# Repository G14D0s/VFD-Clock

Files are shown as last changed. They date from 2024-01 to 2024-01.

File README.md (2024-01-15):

# VFD-Clock
Mein Projekt für LF06: Das Wiedererwecken einer Fluoreszenz-Anzeige. 

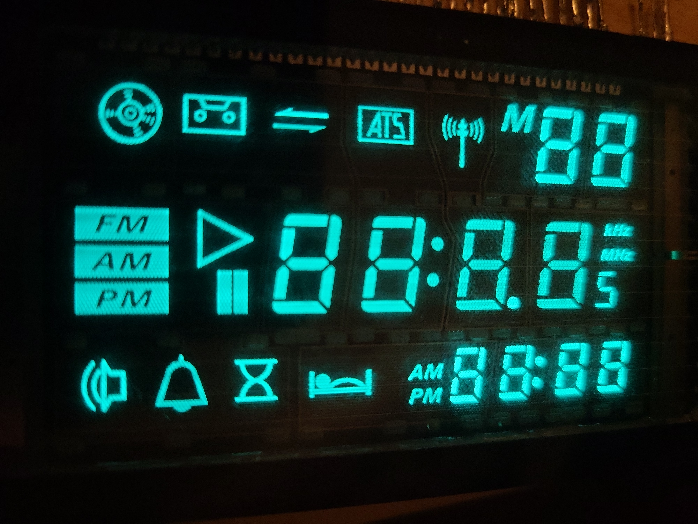
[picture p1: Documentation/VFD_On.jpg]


# Ressourcen
Die Dokumentation / Ausarbeitung findet sich hier:
* [VFD - Ausarbeitung](Documentation/VFD-Ausarbeitung.md)
* [Videos](https://drive.google.com/drive/folders/1unJfzBfumFYsPnYGjSA5P8ESAhW6MluK?usp=sharing)
* [neuester Release mit PDF](https://github.com/G14D0s/VFD-Clock/releases/tag/Release)

***
# Diagramme
Mit [Obsidian](https://obsidian.md/) habe ich folgende Canvas-Dateien erstellt:
* [elektrischer Aufbau/Verbindungen](Documentation/VFD-Aufbau.png)
* [Konzept Programmierung](Documentation/VFD-Bildschirm_Programmierung.png)
* [Ablauf Multiplexing](Documentation/Ablauf_Multiplexing_VFD.png)

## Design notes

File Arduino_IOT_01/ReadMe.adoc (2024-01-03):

:Author: G14D0s
:Email:
:Date: 18/10/2023
:Revision: version#
:License: Public Domain

= Project: {Project}

Describe your project

== Step 1: Installation
Please describe the steps to install this project.

For example:

1. Open this file
2. Edit as you like
3. Release to the World!

== Step 2: Assemble the circuit

Assemble the circuit following the diagram layout.png attached to the sketch

== Step 3: Load the code

Upload the code contained in this sketch on to your board

=== Folder structure

....
 sketch123                => Arduino sketch folder
  ├── sketch123.ino       => main Arduino file
  ├── schematics.png      => (optional) an image of the required schematics
  ├── layout.png          => (optional) an image of the layout
  └── ReadMe.adoc         => this file
....

=== License
This project is released under a {License} License.

=== Contributing
To contribute to this project please contact: 

=== BOM
Add the bill of the materials you need for this project.

|===
| ID | Part name      | Part number | Quantity
| R1 | 10k Resistor   | 1234-abcd   | 10       
| L1 | Red LED        | 2345-asdf   | 5        
| A1 | Arduino Zero   | ABX00066    | 1        
|===

=== Help
This document is written in the _AsciiDoc_ format, a markup language to describe documents. 
If you need help you can search the http://www.methods.co.nz/asciidoc[AsciiDoc homepage]
or consult the http://powerman.name/doc/asciidoc[AsciiDoc cheatsheet]

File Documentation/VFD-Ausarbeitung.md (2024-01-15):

---
tags:
  - Projekte/VFD-Wecker
---
Florian Hoos, EATb26 - 2024-01-15
VFD_On.jpg|600
# 1. Auswahl der Schaltung
Für dieses Projekt habe ich mich entschieden, eine alte Fluoreszenz-Anzeige aus einem auseinandergenommenen Küchenradio wieder funktionstüchtig zu machen. Es handelt sich um ein *Vacuum Fluorescent Display* mit mehreren 7-Segment-Anzeigen und einigen Symbolen auf insgesamt 11 Feldern.
## Warum habe ich diese Schaltung gewählt?
Ich habe die Schaltung der Fluoreszenz-Anzeige gewählt, da sie einige interessante Mechanismen und Funktionsweisen der Elektronik in Anwendung zeigt. Fluoreszenzanzeigen wurden schon vor Jahrzehnten durch LED-Anzeigen ersetzt, die leichter anzusteuern, günstiger zu produzieren und kompakter zu bauen sind. Da wir in Lernfeld 06 aber sowieso "back to basics" gehen und zum Beispiel analoge Transistorschaltungen analysieren, finde ich es sehr passend.
## Welche Problematik löst die Schaltung?
Grundlegend löst die Schaltung kein explizites Problem in meinem Leben. Als historisches Bauteil bietet die Fluoreszenzanzeige aber interessante Vorteile gegenüber regulären LED-Anzeigen. 
So haben sie eine hohe Lebensdauer, einen weiten Sichtwinkel und, zumindest in der Theorie, eine hohe Helligkeit bei exzellentem Kontrast.
# 2. Aufbau der Schaltung 
## Spannungswandler
Für die Spannungsversorgung habe ich ein 12V-Netzteil gewählt.
Für das Projekt benötige ich 3 Spannungsebenen:
1. 5V für den Arduino Nano + IO-Expander
2. 3V für die Filamentspannung
3. 32V für die Anodenspannung
Dementsprechend muss die Spannung runter- und hochgestuft werden. Dafür nutze ich Buck-Converter, da sie eine sehr hohe Effizienz und stufenlose Einstellbarkeit der Ausgangsspannung bieten.
### Buck/Boost-Converter
Buck/Boost Converter sind kompakte Spannungswandler, die mithilfe eines einzelnen ICs (integrierten Schaltkreises) Spannung hoch- oder herunterregeln können.
Diese Schaltungen machen sich die Eigenschaften von Spulen, Kondensatoren und Dioden kombiniert mit einem IC zum geregelten Schalten von Spannung zu nutzen.
Die Funktionsweise der Varianten werden auch in dieser hervorragenden Animation veranschaulicht: `https://youtu.be/vwJYIorz_Aw`

Animation of Buck and Boost Converter (https://www.youtube.com/watch?v=vwJYIorz_Aw)

### Step-Down Converter
Dieser Step-Down Converter basiert auf dem `LM2596S`-IC und nutzt die Eigenschaften von Spulen, Strom zunächst zu blockieren und ihn erst langsam durchzulassen, sowie die energiespeichernden Eigenschaften von Kondensatoren. Der Kondensator wird in regelmäßigen Abständen über den IC mit der Eingangsspannung verbunden, es kann jedoch nur ein begrenzter Strom fließen, da er durch eine Spule ausgebremst wird.
Zwischen der Ausgangsspannung und Gnd befindet sich ein Spannungsteiler, der über ein Potentiometer gesteuert eine Feedback-Spannung an den IC gibt, was die Zeitdauern beeinflusst, die eine Spannung anliegt.
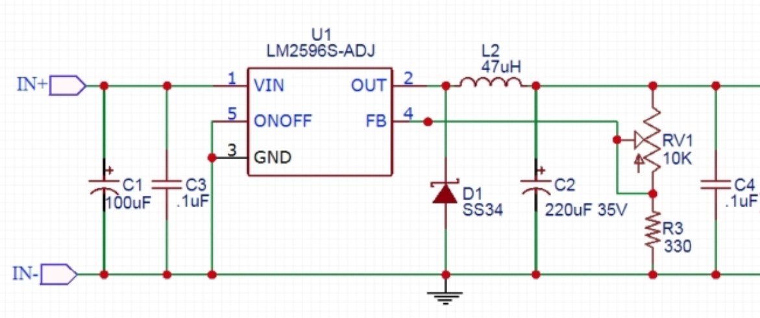
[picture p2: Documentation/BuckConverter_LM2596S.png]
BuckConverter_LM2596S.png|600

*(Beispiel für Buck Converter mit `LM2596S`)*
### Step-Up Converter
Der Step-Up Converter nutzt den `XL6009E1`-IC, der sowohl als Boost- als auch als Buck-Converter genutzt werden kann. 
Anders als beim Step-Down Converter wird hier ein hoher Strom durch die Spule über Pin3 `SW`(Switch) geleitet. Dann schaltet der IC die Verbindung zu Gnd weg; nun fließt der hohe Strom über eine Schottky-Diode zum Ausgang und lädt einen Kondensator auf. Dieser speichert die Energie und entlädt sich langsam, während die Spule wieder "aufgeladen" wird. Auch hier findet sich ein Spannungsteiler, der die Ausgangsspannung über Widerstände und ein Potentiometer an den Feedback Pin des ICs schickt.
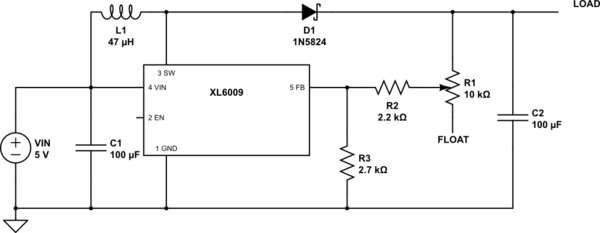
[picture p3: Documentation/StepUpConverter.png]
StepUpConverter.png|600

*(Beispiel für Boost Converter mit `XL6009`)*
## Fluoreszenz-Anzeige
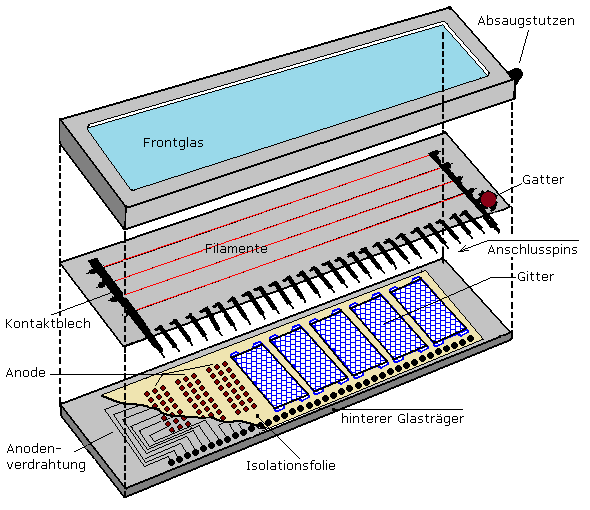
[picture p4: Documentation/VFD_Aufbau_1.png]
VFD_Aufbau_1.png|600

Eine Fluoreszenz-Anzeige funktioniert grundlegend durch die Eigenschaft von Phosphor-Beschichtungen, zu leuchten, wenn sie von Elektronen getroffen werden. Damit sich diese Elektronen frei bewegen können, muss sich das Display in einem Vakuum befinden.
Darum heißt es auf Englisch auf "*Vacuum Fluorescent Display*", oder kurz *VFD*. 
Das VFD zählt zu der Familie der Elektronenröhren, es findet sich in seiner Funktionalität zwischen der Braunschen Röhre (Röhrenfernseher) und der Triode. Es nutzt die Steuerung von Elektronen sowohl zur Beleuchtung als auch zur Verknüpfung mehrerer Felder:
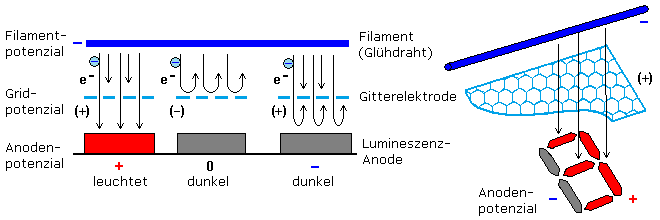
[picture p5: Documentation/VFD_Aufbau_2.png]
VFD_Aufbau_2.png|600

Wie in der Grafik zu sehen ist, können Elektronen die einzelnen Phosphor-beschichteten Anoden nur dann erreichen, wenn sowohl die Anode als auch das Feld eine positive Spannung anliegen haben.
### Multiplexing
Diese Bedingung von anliegender Spannung bei Gitter und Anode kann genutzt werden, um mehrere Anoden über gemeinsame Anschlüsse anzusteuern. 
Dafür schaltet das Programm sich durch die einzelnen Felder und schaltet die Felder an, die für das abzubildende Endergebnis an sein müssen. Diese Grafik zeigt das sehr gut: Die Felder G1 bis G5 werden nacheinander an- und ausgeschaltet, zusätzlich dazu werden die einzelnen Anoden zugeschaltet.
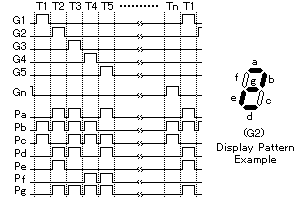
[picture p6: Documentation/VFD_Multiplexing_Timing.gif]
VFD_Multiplexing_Timing.gif|400

Anders als beim starren Ansteuern eines Displays muss nun allerdings das komplette Display etliche Male pro Sekunde durchlaufen werden, um ein konsistentes und flacker-freies Bild zu erschaffen. Dabei wird eine Frequenz von mind. 50Hz empfohlen.
### Filament
Das Filament verläuft über das gesamte Display. Hier liegt eine Spannung von ca. 3V DC an. Die meisten kommerziellen Lösungen arbeiten allerdings mit AC, also Wechselspannung, da so das Display eine gleichbleibende Helligkeit auf der gesamten Länge hat. Je höher die Spannung, desto stärker die Leuchtkraft - jedoch reduziert sich auch die Lebensdauer. Es ist sogar möglich, das Filament zum Schmelzen zu bringen. Daher ist es ratsam, die Spannung so einzustellen, dass es gerade so glüht, dass man das Glühen bei genauerer Betrachtung in einem abgedunkelten Zimmer sehen kann.
Da sich das Filament beim Erwärmen auch ausdehnt, sind alle Filament-Drähte über kleine Federn gespannt, die die Drähte gleichmäßig straff halten.
### Gitter-Anoden
Die Gitter-Anoden sind für das Multiplexing essentiell. Hier sind die einzelnen Zonen gut zu sehen: In jeder Zone befindet sich genau eine 7-Segment Ziffer sowie einige Symbole.
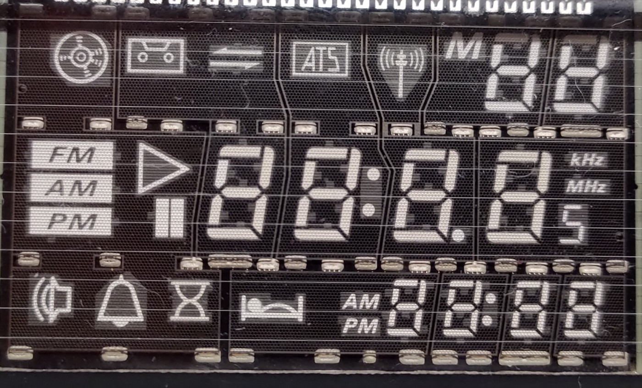
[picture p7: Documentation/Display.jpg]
Display.jpg|500


### Anoden
Die Anoden bilden das letzte Ziel der Elektronen. Hier prallen die Elektronen auf die Phosphorbeschichtung und bringen sie zum Fluoreszieren.
## Darlington-Array
Ein wichtiger Grund, warum Fluoreszenz-Anzeigen an Popularität verloren haben, ist die Tatsache, dass sie mit Spannung bis über 30 Volt arbeiten. LED-Anzeigen hingegen operieren oft mit Spannungen von 5V oder sogar 3.3V, daher ist es deutlich leichter, sie anzusteuern.
Für VFDs hingegen benötigt man irgendeine Möglichkeit, von z.B. 5V Logik-Pegel auf 32V zu schalten. Das geht am besten mit sogenannten Darlington-Arrays. 
Eine Darlington-Schaltung entsteht durch das Verketten von Transistoren, um eine enorme Stromverstärkung zu ermöglichen. Der untere Schaltkreis ist der eines einzelnen Treibers aus einem Darlington-Array. Hier werden 8 solcher Darlington-Treiber mit gemeinsamer Spannungsversorgung bereitgestellt. Dieser IC ist speziell für das Betreiben von Fluroreszenz-Anzeigen entwickelt worden.
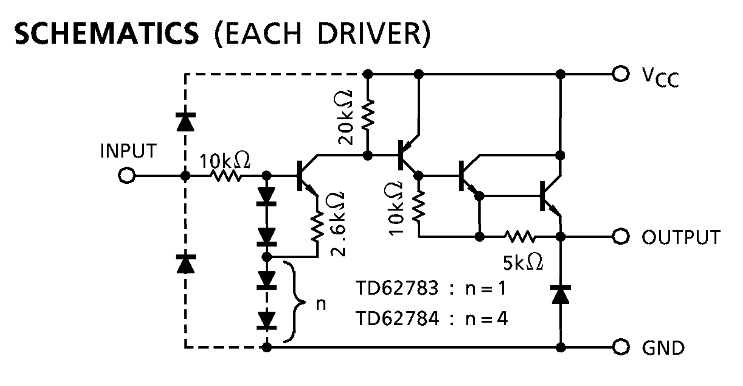
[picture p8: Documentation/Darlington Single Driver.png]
Darlington Single Driver.png|500


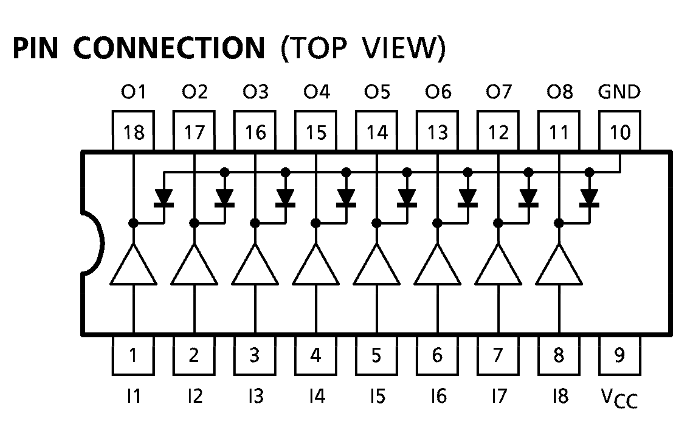
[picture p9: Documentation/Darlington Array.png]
Darlington Array.png|500


## weitere Bauteile
### Arduino Nano
Der Arduino Nano hat sich schon seit langer Zeit für die verschiedensten Projekte erwiesen. Er ist klein, verlässlich und hat den Support einer riesigen Bastler-Community hinter sich, was die meisten Projekte deutlich erleichtert.  
### IO-Expander: MCP23017
Leider bietet der Arduino Nano nur 13 digitale Ausgänge, was nicht zum Ansteuern der Fluoreszenzanzeige ausreicht. Daher verwende ich hier einen IO-Expander, der die zusätzlichen Ausgänge zur Verfügung stellt.
### RTC-Modul
Um dem Projekt auch praktisches Nutzen zu geben, habe ich ein RTC (Real Time Clock)-Modul verbaut. Die aktuelle Uhrzeit wird vom Arduino ausgelesen und auf dem VFD angezeigt.
# 3. Schaltpläne und Konzepte
Als EDA-Programm meiner Wahl verwende ich KiCad, da ich so auf die Ressourcen einer sehr großen Community zurückgreifen kann. Außerdem ist es Open-Source, was heutzutage immer wichtiger wird.
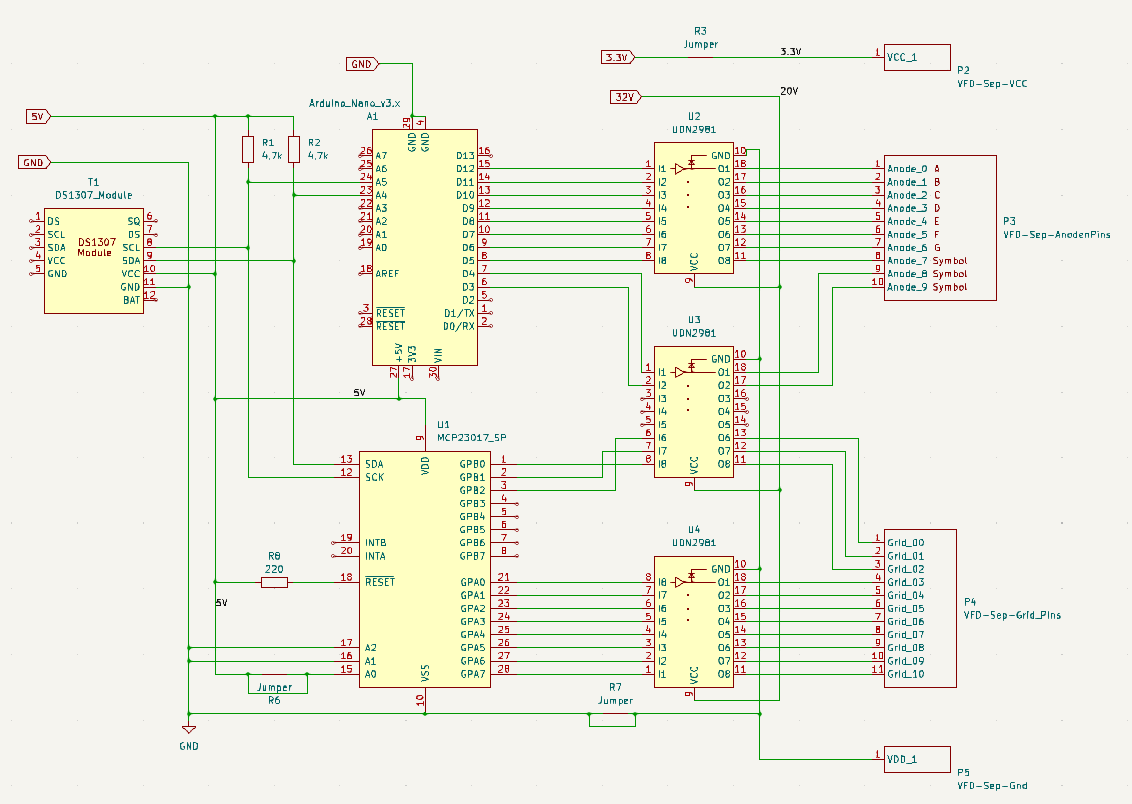
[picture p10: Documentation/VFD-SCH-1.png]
VFD-SCH-1.png|700


Hier zu sehen ist der Schaltplan für den Arduino Nano, den IO-Expander, das RTC-Modul, die Darlington-Arrays sowie die Anschlüsse für das Fluoreszenz-Display. Für letzteres habe ich eigene Bauteile erstellt.
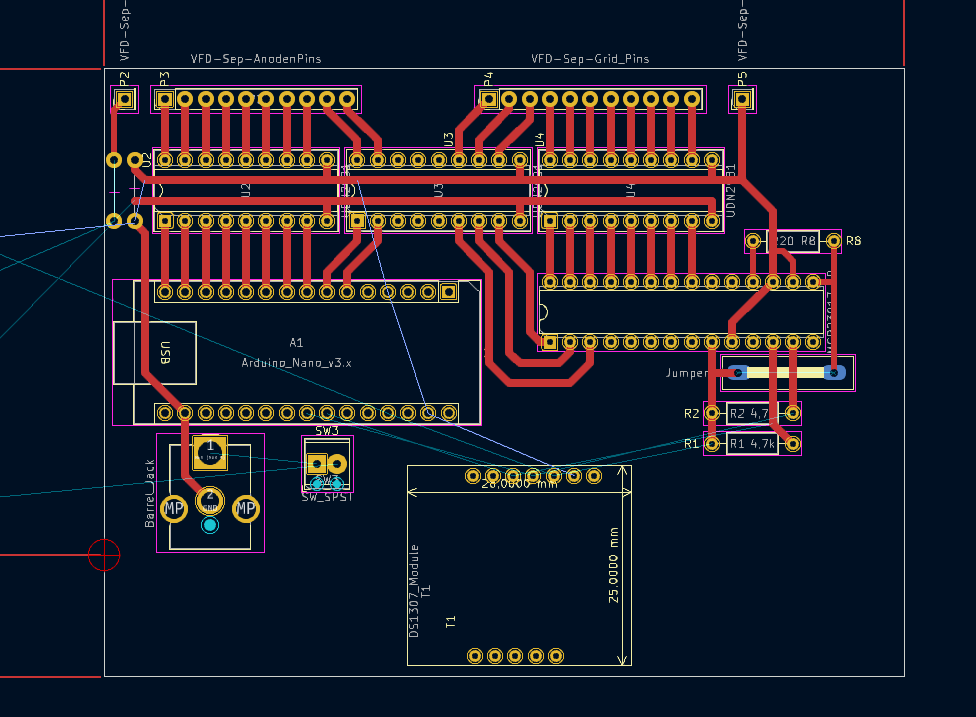
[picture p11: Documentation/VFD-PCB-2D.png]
VFD-PCB-2D.png|600


Hier ist ein möglicher Aufbau auf einer Leiterplatte. Leider habe ich hierfür keine Zeit oder Ressourcen mehr gehabt, weswegen das Projekt zunächst als Proof of Concept auf mehreren Breadboards lebt.
Für diesen Aufbau habe ich den obigen Schaltkreis optimiert, auch die Darstellung in 3D hat hierbei geholfen.
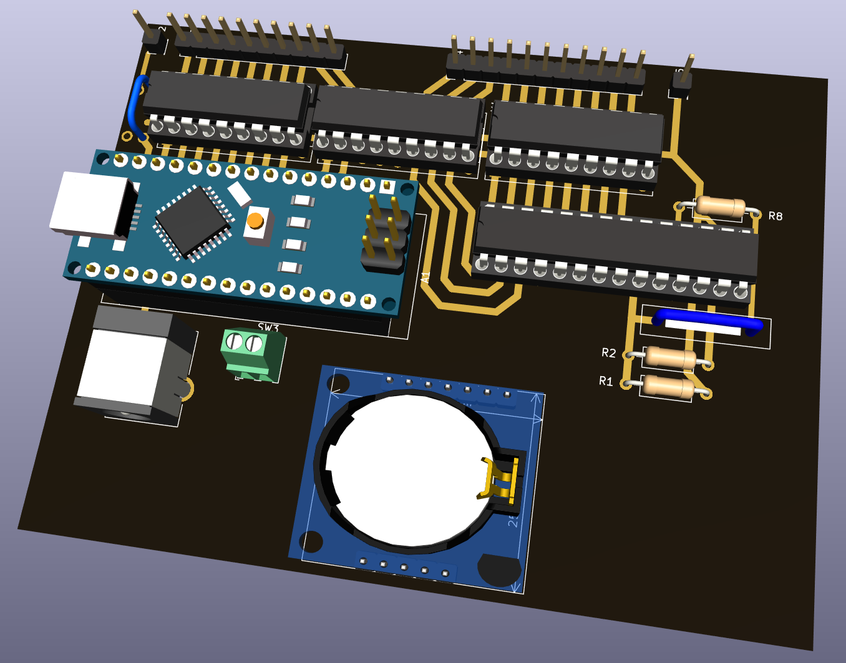
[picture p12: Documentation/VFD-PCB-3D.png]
VFD-PCB-3D.png|600


# 4. Programmierung
Das finale Ergebnis des Projektes ist eine Uhr, die die Stunden, Minuten und Sekunden anzeigt.
Hierfür habe ich ein Arduino-Programm mit mehreren Subroutinen geschrieben, was für eine deutlich übersichtlichere Struktur sorgt.
So besteht mein `void loop()` aus nur 3 Befehlen:
```C++
void loop() {
  RTC_UhrzeitErfassen();  // abspeichern der Zeit in Variabeln
  UhrzeitZuArray();       // Übersetzen der Zeit in Array
  // Ansteuern des Displays mit Werten aus dem Array:
  VFDAnsteuerung(50,100); // frequenz von 50 und Helligkeit von 100%
}
```

# 5. Fazit
Ich bin mit dem Endergebnis größtenteils zufrieden. Das Schulprojekt hat mir die Gelegenheit geboten, mich wieder einmal mit diesem spannenden Thema zu befassen und Neues zu lernen. Leider bin ich wieder am Zeit-Management gescheitert, wobei auch hier externe Faktoren dazuzählten. Für ein Projekt, dass man mal eben neben Schule & Ausbildung auf die Beine stellt, war dieses vermutlich etwas hoch gegriffen.

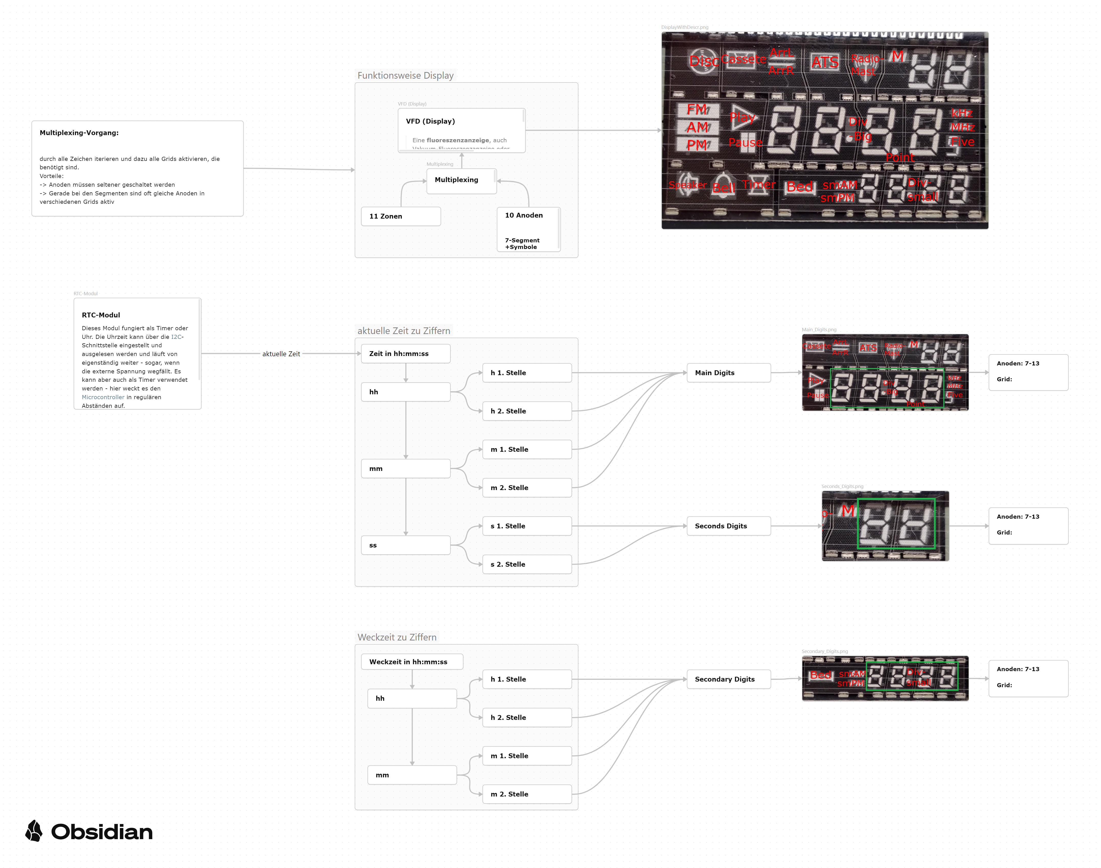
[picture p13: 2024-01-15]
Documentation/VFD-Bildschirm_Programmierung.png

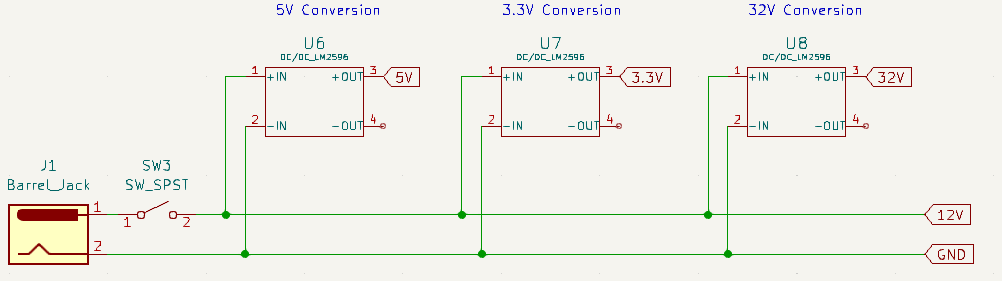
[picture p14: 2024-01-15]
Documentation/VFD-SCH-2.png

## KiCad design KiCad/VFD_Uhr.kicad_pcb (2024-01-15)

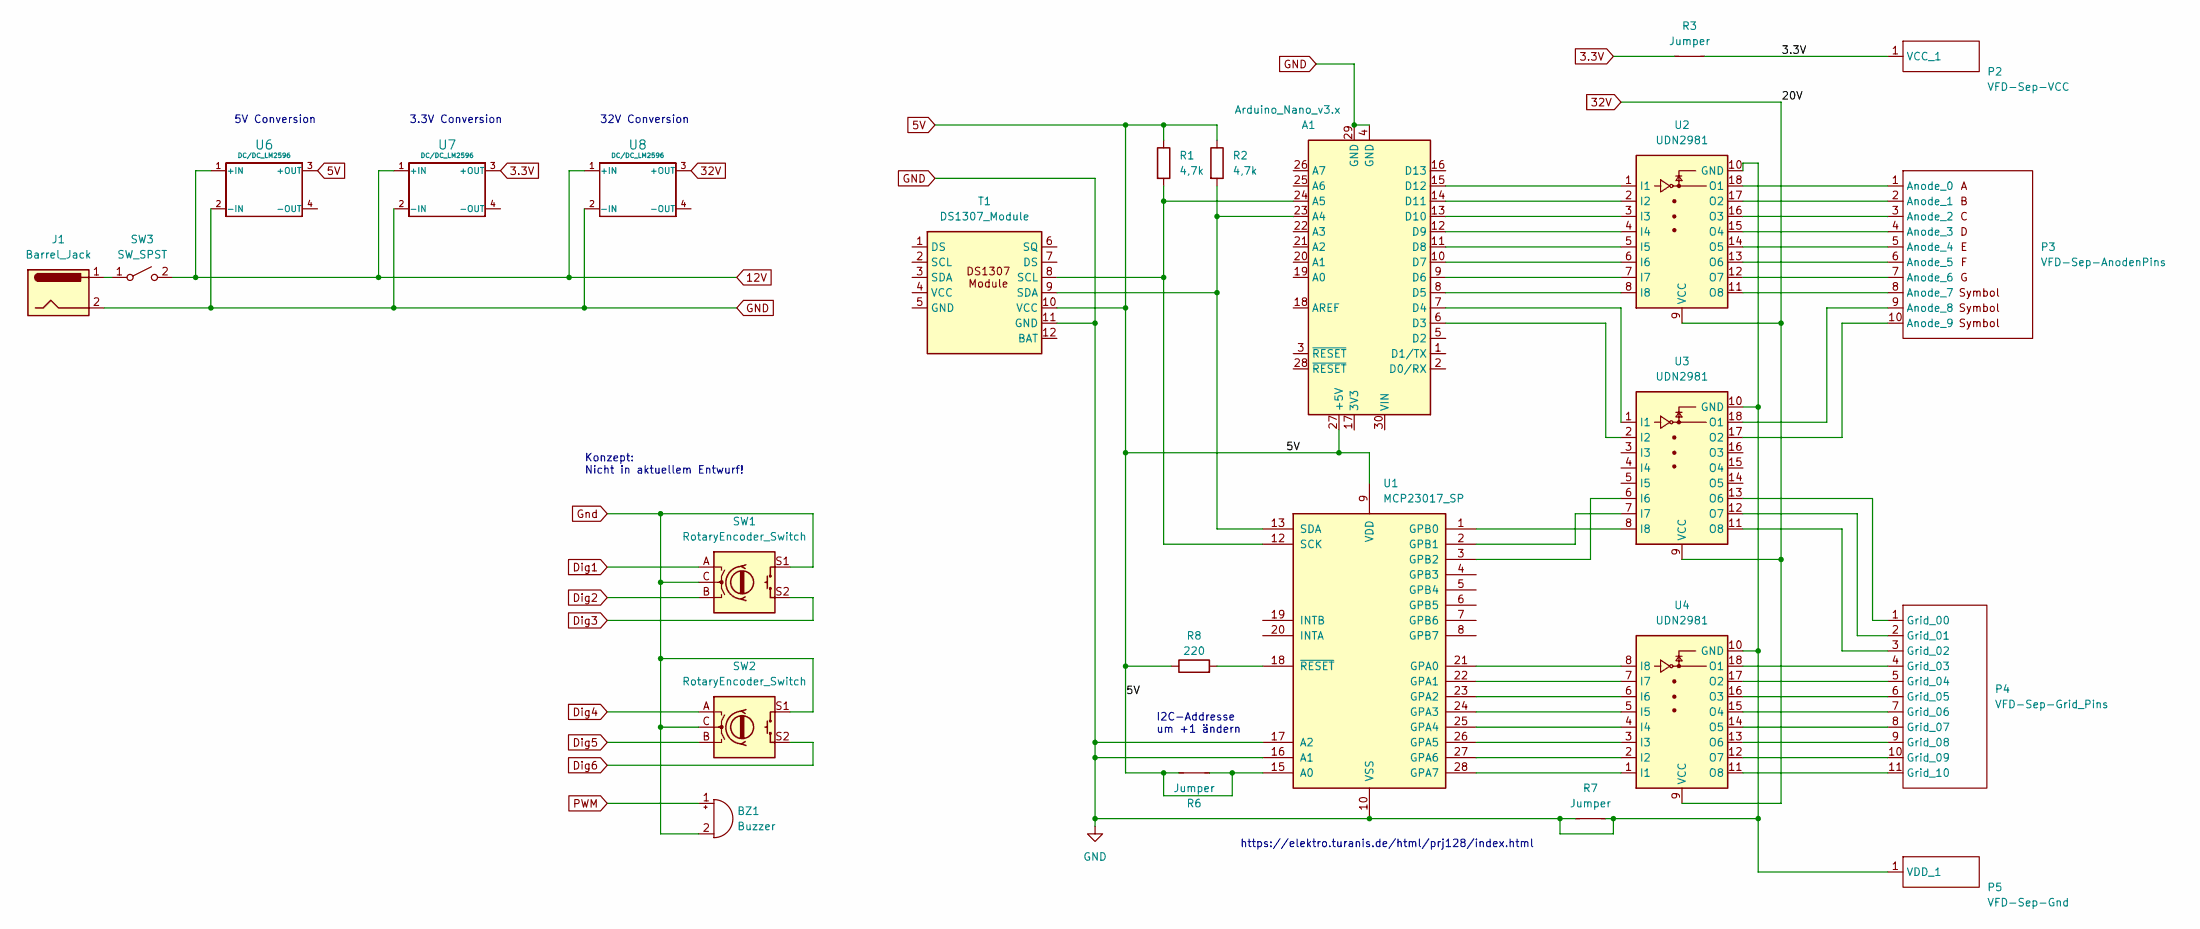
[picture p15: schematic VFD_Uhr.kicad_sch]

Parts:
A1: Arduino_Nano_v3.x; Arduino_Nano
BZ1: Buzzer; Buzzer_12x9.5RM7.6
J1: Barrel_Jack; BarrelJack_CUI_PJ-063AH_Horizontal_CircularHoles
P2: VFD-Sep-VCC; PinHeader_1x01_P2.54mm_Vertical
P3: VFD-Sep-AnodenPins; PinHeader_1x10_P2.54mm_Vertical
P4: VFD-Sep-Grid_Pins; PinHeader_1x11_P2.54mm_Vertical
P5: VFD-Sep-Gnd; PinHeader_1x01_P2.54mm_Vertical
R1, R2: 4,7k; R_Axial_DIN0207_L6.3mm_D2.5mm_P10.16mm_Horizontal
R3, R7: Jumper; 0-Resistor Jumper
R6: Jumper; Jumper-Wire_12mm_Red
R8: 220; R_Axial_DIN0207_L6.3mm_D2.5mm_P10.16mm_Horizontal
SW1, SW2: RotaryEncoder_Switch; RotaryEncoder_Alps_EC11E-Switch_Vertical_H20mm
SW3: SW_SPST; TerminalBlock_Phoenix_MPT-0,5-2-2.54_1x02_P2.54mm_Horizontal
T1: DS1307_Module
U1: MCP23017_SP; DIP-28_W7.62mm
U2, U3, U4: UDN2981; DIP-18_W7.62mm_Socket
U6, U7, U8: DC/DC_LM2596; DC_DC_LM2596_small

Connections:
3.3V: P2.1 (VCC_1), R3.1, R3.2, U7.3 (+OUT)
5V: A1.27 (+5V), R1.1, R2.1, R6.1, R6.2, R8.1, T1.10 (VCC), U1.9 (VDD), U1.15 (A0), U6.3 (+OUT)
12V: SW3.2 (B), U6.1 (+IN), U7.1 (+IN), U8.1 (+IN)
32V: U2.9 (VCC), U3.9 (VCC), U4.9 (VCC), U8.3 (+OUT)
Dig1: SW1.A
Dig2: SW1.B
Dig3: SW1.S2
Dig4: SW2.A
Dig5: SW2.B
Dig6: SW2.S2
GND: A1.4 (GND), A1.29 (GND), J1.2, P5.1 (VDD_1), R7.1, R7.2, T1.11 (GND), U1.10 (VSS), U1.16 (A1), U1.17 (A2), U2.10 (GND), U3.10 (GND), U4.10 (GND), U6.2 (-IN), U7.2 (-IN), U8.2 (-IN)
Gnd: BZ1.2 (+), SW1.C, SW1.S1, SW2.C, SW2.S1
unnamed: A1.23 (A4), R2.2, T1.9 (SDA), U1.13 (SDA)
unnamed: A1.24 (A5), R1.2, T1.8 (SCL), U1.12 (SCK)
unnamed: A1.6 (D3), U3.2 (I2)
unnamed: A1.7 (D4), U3.1 (I1)
unnamed: A1.8 (D5), U2.8 (I8)
unnamed: A1.9 (D6), U2.7 (I7)
unnamed: A1.10 (D7), U2.6 (I6)
unnamed: A1.11 (D8), U2.5 (I5)
unnamed: A1.12 (D9), U2.4 (I4)
unnamed: A1.13 (D10), U2.3 (I3)
unnamed: A1.14 (D11), U2.2 (I2)
unnamed: A1.15 (D12), U2.1 (I1)
unnamed: P3.1 (Anode_0), U2.18 (O1)
unnamed: P3.2 (Anode_1), U2.17 (O2)
unnamed: P3.3 (Anode_2), U2.16 (O3)
unnamed: P3.4 (Anode_3), U2.15 (O4)
unnamed: P3.5 (Anode_4), U2.14 (O5)
unnamed: P3.6 (Anode_5), U2.13 (O6)
unnamed: P3.7 (Anode_6), U2.12 (O7)
unnamed: P3.8 (Anode_7), U2.11 (O8)
unnamed: P3.9 (Anode_8), U3.18 (O1)
unnamed: P3.10 (Anode_9), U3.17 (O2)
unnamed: P4.1 (Grid_00), U3.13 (O6)
unnamed: P4.2 (Grid_01), U3.12 (O7)
unnamed: P4.3 (Grid_02), U3.11 (O8)
unnamed: P4.4 (Grid_03), U4.18 (O1)
unnamed: P4.5 (Grid_04), U4.17 (O2)
unnamed: P4.6 (Grid_05), U4.16 (O3)
unnamed: P4.7 (Grid_06), U4.15 (O4)
unnamed: P4.8 (Grid_07), U4.14 (O5)
unnamed: P4.9 (Grid_08), U4.13 (O6)
unnamed: P4.10 (Grid_09), U4.12 (O7)
unnamed: P4.11 (Grid_10), U4.11 (O8)
unnamed: J1.1, SW3.1 (A)
unnamed: U1.21 (GPA0), U4.8 (I8)
unnamed: U1.22 (GPA1), U4.7 (I7)
unnamed: U1.23 (GPA2), U4.6 (I6)
unnamed: U1.24 (GPA3), U4.5 (I5)
unnamed: U1.25 (GPA4), U4.4 (I4)
unnamed: U1.26 (GPA5), U4.3 (I3)
unnamed: U1.27 (GPA6), U4.2 (I2)
unnamed: U1.28 (GPA7), U4.1 (I1)
unnamed: U1.1 (GPB0), U3.8 (I8)
unnamed: U1.2 (GPB1), U3.7 (I7)
unnamed: U1.3 (GPB2), U3.6 (I6)
unnamed: R8.2, U1.18 (~RESET)
PWM: BZ1.1 (-)

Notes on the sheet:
5V Conversion
3.3V Conversion
https://elektro.turanis.de/html/prj128/index.html
32V Conversion
Konzept: Nicht in aktuellem Entwurf!
I2C-Addresse um +1 ändern

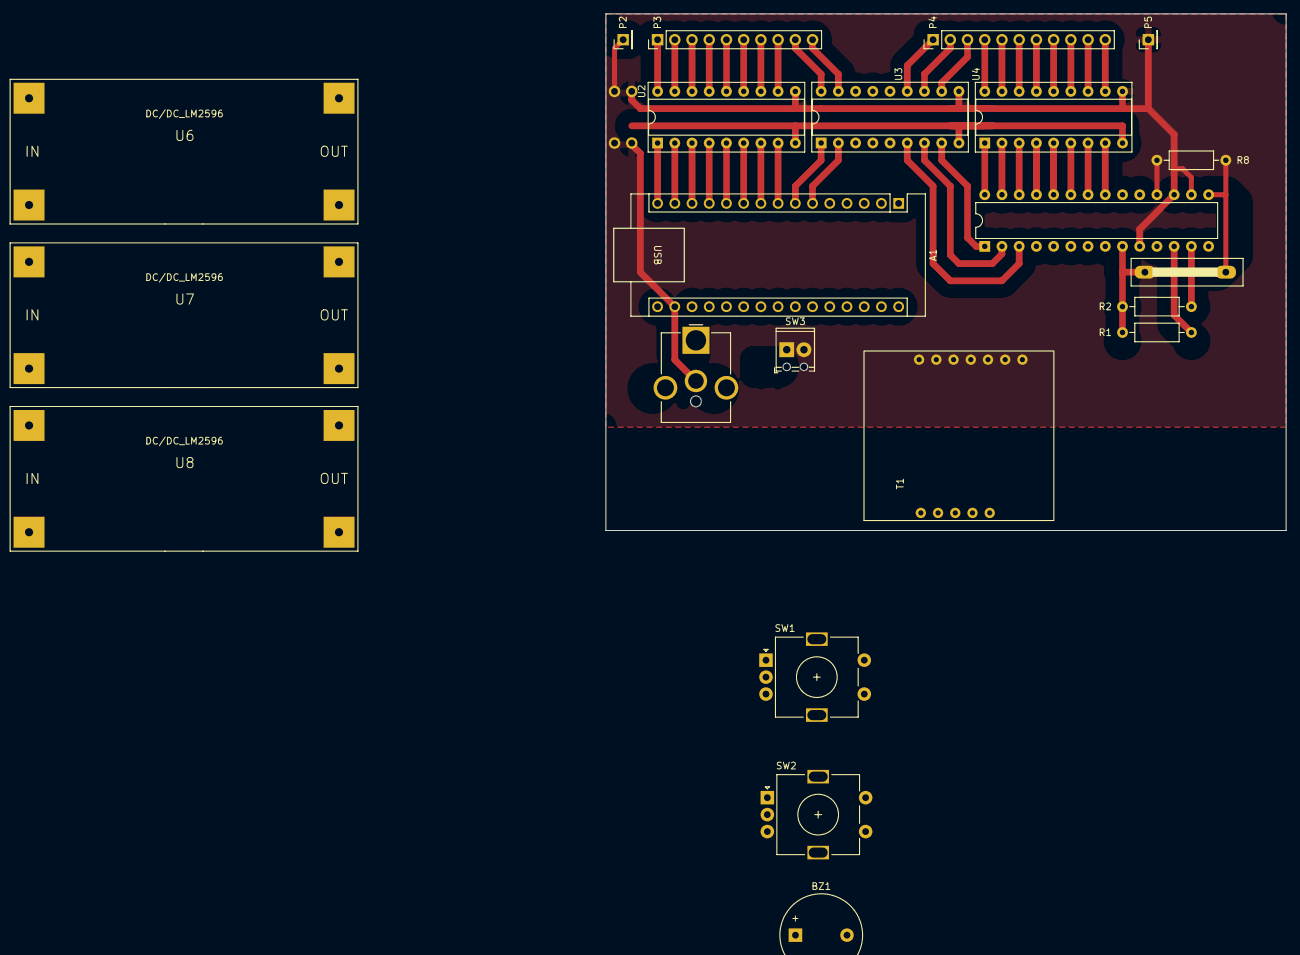
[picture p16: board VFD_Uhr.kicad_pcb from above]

Board: 2 copper layers, 100.3 x 76.2 mm, 24 parts (0 on the bottom side), 52 nets.

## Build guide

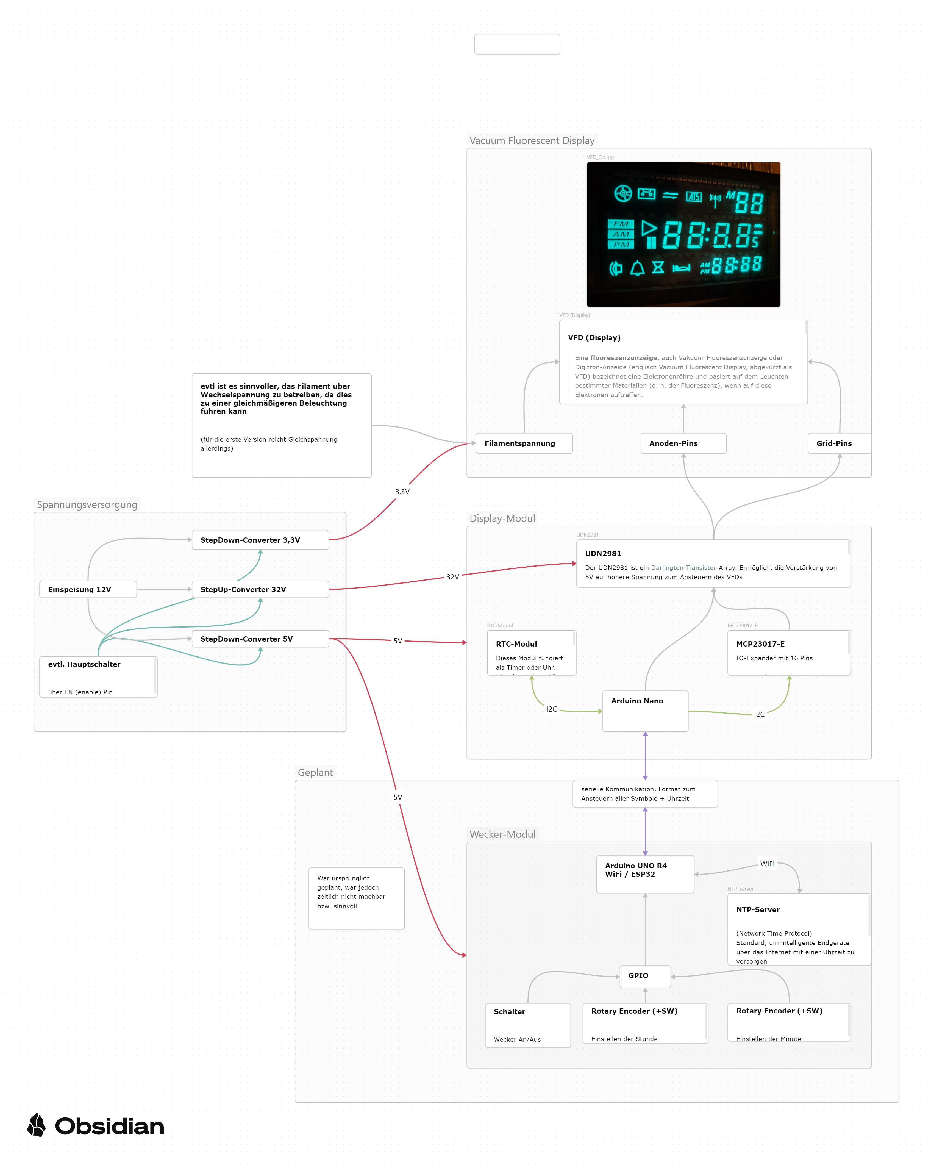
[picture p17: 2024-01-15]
Documentation/VFD-Aufbau.png

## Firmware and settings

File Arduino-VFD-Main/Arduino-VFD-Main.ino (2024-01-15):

// developed by Florian Hoos, 2024-01-15
#include <Wire.h>
#include <Adafruit_MCP23X17.h>
Adafruit_MCP23X17 mcp1;

#include <TimeLib.h>
#include <DS1307RTC.h> // gilt auch für DS3231

// externe variablen können über verschiedene Sketche in einem ordner verwendet werden.
extern unsigned long currentMillis;
extern unsigned long seconds;
extern unsigned long minutes;
extern unsigned long hours;
extern unsigned long days;

extern bool VFDTabelle[11][10];
extern bool Zahlen[10] [7];

void setup() {
  Serial.begin(115200);

  if (!mcp1.begin_I2C(0x21)) { //0,&Wire
    Serial.println("Error.");
    while (1);
  }else{
    Serial.println("I2C Success!");
  }

  // initialisieren aller Ausgänge
  for (byte i = 0; i <=  15; i++) {
    mcp1.pinMode(i, OUTPUT);
  }
  for (byte i = 0; i <= 13; i++){
    pinMode(i, OUTPUT);
  }
}

void loop() {
  RTC_UhrzeitErfassen();  // abspeichern der Zeit in Variabeln
  //printTime();
  UhrzeitZuArray();       // Übersetzen der Zeit in Array
  //ArrayAusdruck(VFDTabelle);
                          // Ansteuern des Displays mit Werten aus dem Array 
  VFDAnsteuerung(50,100); // frequenz von 50 und Helligkeit von 100%
}

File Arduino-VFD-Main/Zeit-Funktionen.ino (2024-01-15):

// developed by Florian Hoos, 2024-01-15
bool VFDTabelle[11][10]{
// Anoden: 
// A,B,C,D,E,F,G,7,8,9     Grids:
  {0,0,0,0,0,0,0,0,0,0},// 0
  {0,0,0,0,0,0,0,0,0,0},// 1
  {0,0,0,0,0,0,0,0,0,0},// 2
  {0,0,0,0,0,0,0,0,0,0},// 3
  {0,0,0,0,0,0,0,0,0,0},// 4 
  {0,0,0,0,0,0,0,0,0,0},// 5 H
  {0,0,0,0,0,0,0,0,0,0},// 6 M
  {0,0,0,0,0,0,0,0,0,0},// 7 M
  {0,0,0,0,0,0,0,0,0,0},// 8 S
  {0,0,0,0,0,0,0,0,0,0},// 9 S
  {0,0,0,0,0,0,0,0,0,0} //10 M
};

// zum übersetzen der zahlen in 7-Segment
bool Zahlen[10] [7] =
{
  //a, b, c, d, e, f, g
  {1, 1, 1, 1, 1, 1, 0}, //0
  {0, 1, 1, 0, 0, 0, 0}, //1
  {1, 1, 0, 1, 1, 0, 1}, //2
  {1, 1, 1, 1, 0, 0, 1}, //3
  {0, 1, 1, 0, 0, 1, 1}, //4
  {1, 0, 1, 1, 0, 1, 1}, //5
  {1, 0, 1, 1, 1, 1, 1}, //6
  {1, 1, 1, 0, 0, 0, 0}, //7
  {1, 1, 1, 1, 1, 1, 1}, //8
  {1, 1, 1, 1, 0, 1, 1}  //9
};

  unsigned long currentMillis;
  unsigned long seconds;
  unsigned long minutes;
  unsigned long hours;
  unsigned long days;


void UhrzeitErfassen(){
  currentMillis = millis();
  seconds = currentMillis / 1000;
  minutes = seconds / 60;
  hours = minutes / 60;
  days = hours / 24;
  currentMillis %= 1000;
  seconds %= 60;
  minutes %= 60;
  hours %= 24;
}

void printTime(){
  Serial.print(hours);
  Serial.print(":");
  Serial.print(minutes);
  Serial.print(":");
  Serial.println(seconds);
  Serial.print(days);
  Serial.println(" Days");
}


void UhrzeitZuArray(){

  PartAndPassValue(hours,   5, 6);
  PartAndPassValue(minutes, 7,10);
  PartAndPassValue(seconds, 8, 9);
  LightUpBigDIv(seconds,6);


}
void LightUpBigDIv(int Time, int Pos){
  if(Time%2==0||Time==0){
    VFDTabelle[Pos][7]=1;
  }else{
    VFDTabelle[Pos][7]=0;
  }
}
void PartAndPassValue(int Time, int Pos1, int Pos2){
  int T1 = Time/10;
  int T2 = Time%10;

  WriteInArray(T1,Pos1);
  WriteInArray(T2,Pos2);
}

void WriteInArray(int ZahlWert,int ChosenRow){
  for(int i=0;i<7;i++){
    VFDTabelle[ChosenRow][i] = Zahlen[ZahlWert][i];
  }
}


void ArrayAusdruck(bool PrintArray[11][10]){
  Serial.println("Array:");
  for(int PrintRows = 0;PrintRows<11;PrintRows++){
    for(int PrintCols = 0;PrintCols<9;PrintCols++){
      Serial.print(PrintArray[PrintRows][PrintCols]);
      Serial.print(",");
    }
    Serial.println(PrintArray[PrintRows][9]);
  }
  Serial.println();
}


//################### RTC-DS1307 ###################
void RTC_UhrzeitErfassen(){
  tmElements_t tm;

  if (RTC.read(tm)) {
    // Serial.print("Ok, Time = ");
    // print2digits(tm.Hour);
    // Serial.write(':');
    // print2digits(tm.Minute);
    // Serial.write(':');
    // print2digits(tm.Second);
    // Serial.print(", Date (D/M/Y) = ");
    // Serial.print(tm.Day);
    // Serial.write('/');
    // Serial.print(tm.Month);
    // Serial.write('/');
    // Serial.print(tmYearToCalendar(tm.Year));
    // Serial.println();
    hours=tm.Hour;
    minutes=tm.Minute;
    seconds=tm.Second;
  } 
  else {
    if (RTC.chipPresent()) {
      Serial.println("The DS1307 is stopped.  Please run the SetTime");
      Serial.println("example to initialize the time and begin running.");
      Serial.println();
    } else {
      Serial.println("DS1307 read error!  Please check the circuitry.");
      Serial.println();
      UhrzeitErfassen();
    }
  }
}


void print2digits(int number) {
  if (number >= 0 && number < 10) {
    Serial.write('0');
  }
  Serial.print(number);
}
